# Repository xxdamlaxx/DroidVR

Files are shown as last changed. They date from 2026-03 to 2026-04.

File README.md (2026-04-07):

# 🥽 DroidVR

A DIY VR controller ecosystem — open-source hardware and firmware for SteamVR-compatible motion controllers.

---

## License

DroidVR is available under a **dual license** model. Pick whichever fits your use case.

### Option 1 — Free & Open (Attribution Required)

Use, modify, distribute, and sell DroidVR for free, as long as you provide clear and visible attribution in your project's documentation, about page, and repository.

**Required attribution:**

> Built with **DroidVR** by [xxdamlaxx](https://github.com/xxdamlaxx)

See [`LICENSE.md`](LICENSE.md) for full terms.

### Option 2 — Commercial License (No Attribution)

If you prefer not to include attribution, you can purchase a commercial license:

| Tier | Monthly Fee |
|---|---|
| Public / Open-Source Development | $500 / month |
| Private / Closed-Source Development | $5,000 / month |

- Prices may be adjusted at the end of each calendar year.
- No refunds.

See [`LICENSE-COMMERCIAL.md`](LICENSE-COMMERCIAL.md) for full terms.

---

## Contact

For commercial licensing inquiries, reach out via [GitHub](https://github.com/xxdamlaxx) or email *(coming soon)*.

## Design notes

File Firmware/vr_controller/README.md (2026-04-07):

# DIY VR Sağ Kol Kontrolcü

## Donanım

**Verici (kol):** BluePill STM32F103C8T6
- MPU6500 (I2C): SCL→PB6, SDA→PB7
- NRF24L01 (SPI1): SCK→PA5, MISO→PA6, MOSI→PA7, CSN→PA4, CE→PB0
- Joystick: VRx→PA0, VRy→PA1, SW→PB10
- Tetik pot (20K): Signal→PA3
- VCC→3.3V, GND→GND (hepsi)
- NRF24 VCC-GND arasına 10-100µF kapasitör

**Alıcı (PC):** Wemos D1 Mini + E01-ML01DP5
- SCK→D5, MISO→D6, MOSI→D7, CSN→D8, CE→D1
- VCC→3.3V, GND→GND

## Arduino IDE Kurulumu

### Kütüphaneler (Library Manager'dan kur):
- RF24 by TMRh20

### Verici board ayarları:
- Board: Generic STM32F1 series
- Board part number: BluePill F103C8
- Upload method: STLink veya Serial

### Alıcı board ayarları:
- Board: LOLIN(WEMOS) D1 mini

## SteamVR Sürücü Derleme

1. OpenVR SDK indir: https://github.com/ValveSoftware/openvr → C:\openvr'a çıkar
2. Visual Studio 2022 Community kur (C++ Desktop development workload)
3. CMake kur: https://cmake.org/download/
4. Komut satırında:
```
cd steamvr_driver
mkdir build && cd build
cmake .. -DOPENVR_SDK_DIR="C:/openvr"
cmake --build . --config Release
```
5. `diyvr` klasörünü kopyala: `Steam\steamapps\common\SteamVR\drivers\diyvr`
6. `default.vrsettings` içinde COM port numarasını düzenle (Wemos hangi porta bağlıysa)

## Test

1. Vericiye kodu yükle, Serial Monitor'de "Verici hazir!" mesajını gör
2. Alıcıya kodu yükle, Serial Monitor'de "$VR,..." verilerini gör
3. SteamVR'ı aç, sağ el kontrolcüsü görünmeli
4. Kolu hareket ettirince SteamVR'da dönmeli

## Notlar

- Bu 3DOF (sadece rotasyon). Pozisyonel tracking yok.
- MPU6500 sahte çıkarsa WHO_AM_I 0x70 dönmez, Serial'de hata mesajı görürsün.
- MPU6050 da destekleniyor (0x68 döner), otomatik algılar.
- default.vrsettings'de offset değerleri kontrolcünün SteamVR'daki sabit pozisyonunu belirler.

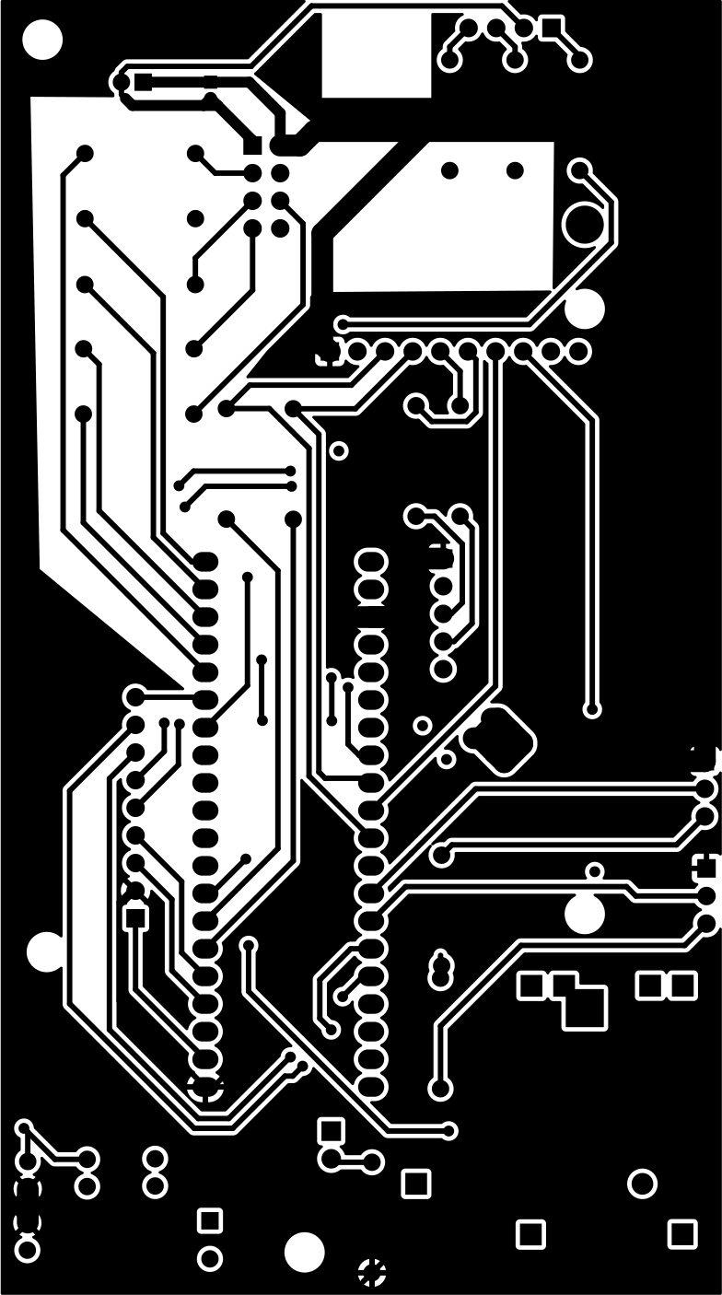
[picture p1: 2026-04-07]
EasyDroidVR_PCB/EasyDroidVR_PCB-backups.png

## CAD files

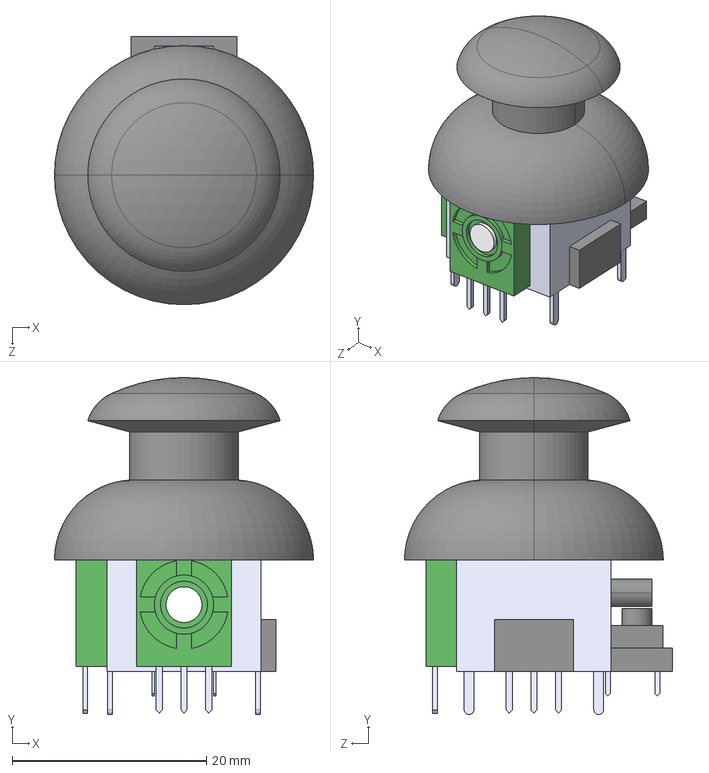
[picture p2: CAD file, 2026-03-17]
EasyDroidVR_PCB/COM-09032/COM-09032.step
26.7 x 34.7 x 27.6 mm

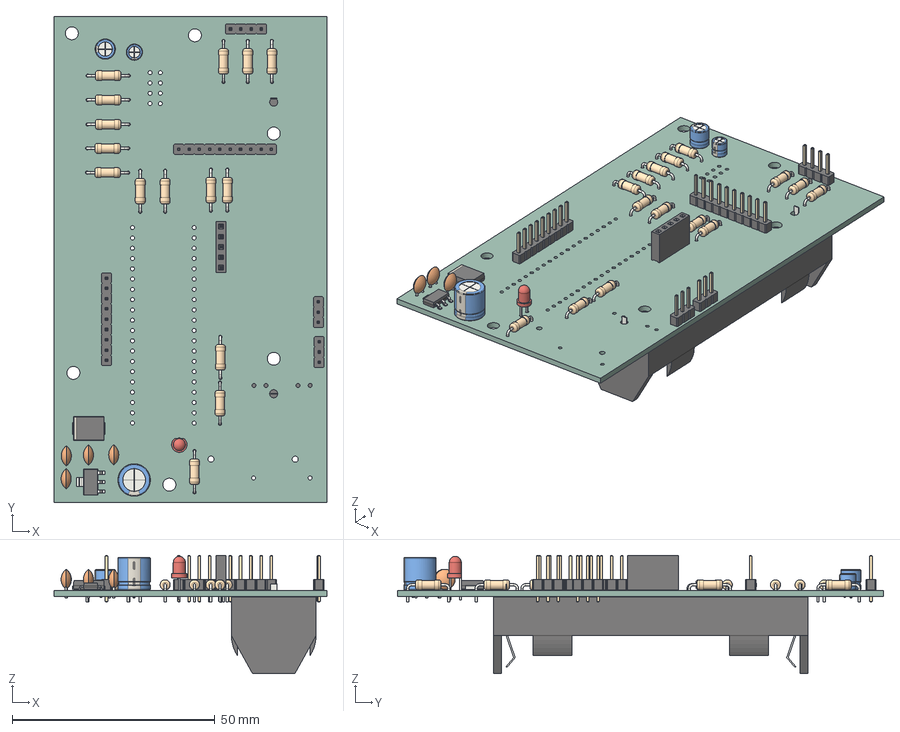
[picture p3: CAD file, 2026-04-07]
EasyDroidVR_PCB/EasyDroidVR_PCB.step
67.3 x 120.0 x 29.2 mm
R_Axial_DIN0207_L6.3mm_D2.5mm_P10.16mm_Horizontal x 15
LED_D3.0mm
C_Disc_D5.0mm_W2.5mm_P2.50mm x 4
PinHeader_1x03_P2.54mm_Vertical x 2
CP_Radial_D5.0mm_P2.00mm
PinHeader_1x09_P2.54mm_Vertical
PinHeader_1x10_P2.54mm_Vertical
CP_Radial_D4.0mm_P1.50mm
PinHeader_1x04_P2.54mm_Vertical
D_SMC
CP_Radial_D8.0mm_P3.50mm
PinSocket_1x05_P2.54mm_Vertical
SOT-223
BatteryHolder_MPD_BH-18650-PC2
EasyDroidVR_PCB_PCB

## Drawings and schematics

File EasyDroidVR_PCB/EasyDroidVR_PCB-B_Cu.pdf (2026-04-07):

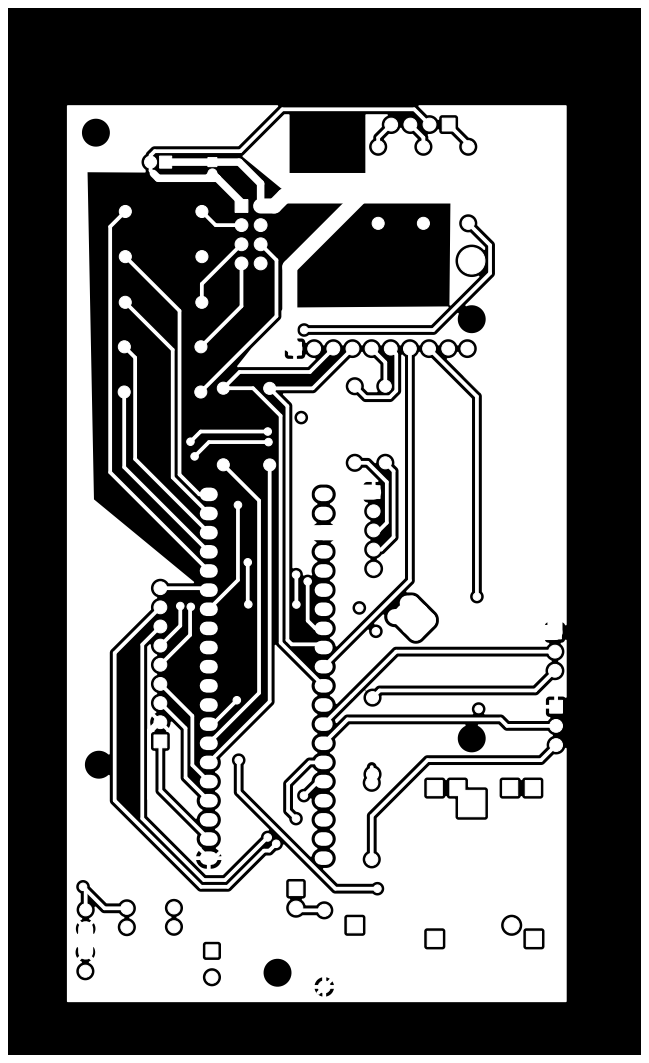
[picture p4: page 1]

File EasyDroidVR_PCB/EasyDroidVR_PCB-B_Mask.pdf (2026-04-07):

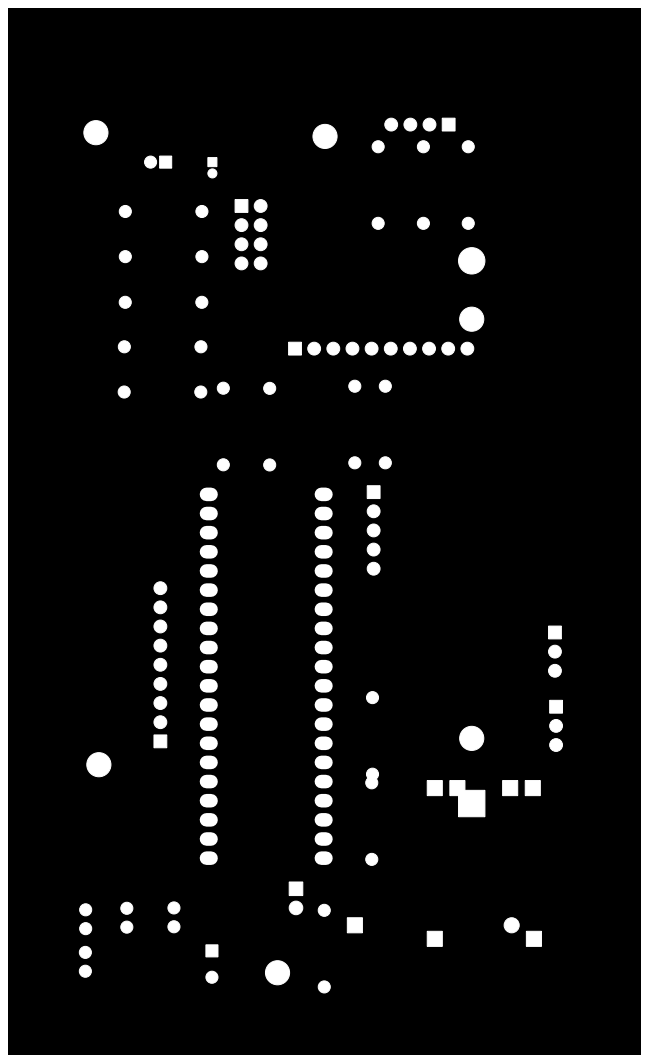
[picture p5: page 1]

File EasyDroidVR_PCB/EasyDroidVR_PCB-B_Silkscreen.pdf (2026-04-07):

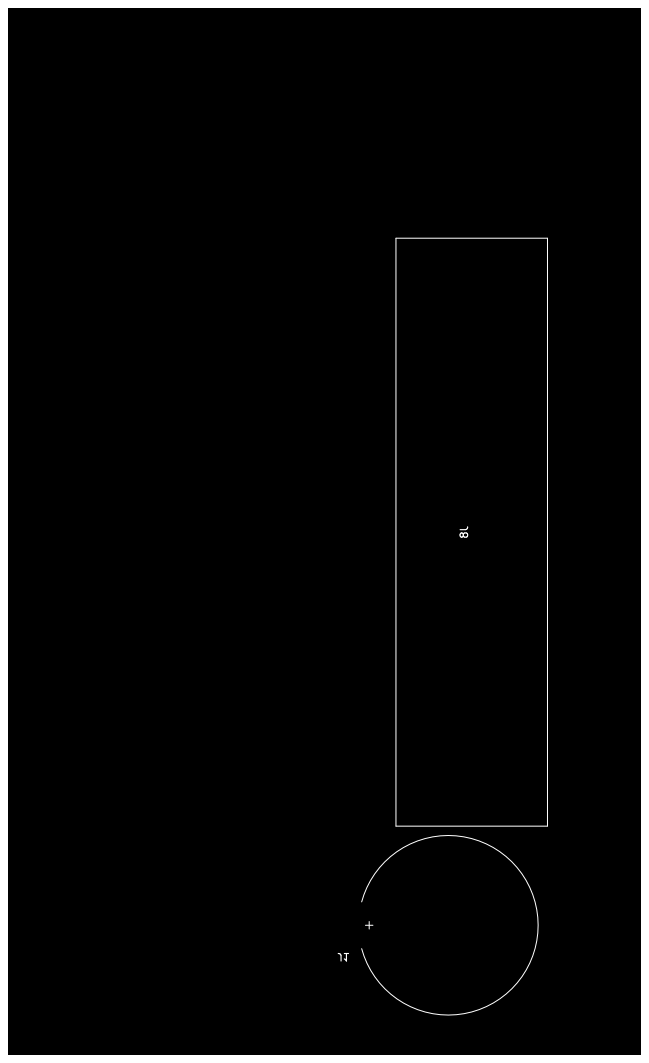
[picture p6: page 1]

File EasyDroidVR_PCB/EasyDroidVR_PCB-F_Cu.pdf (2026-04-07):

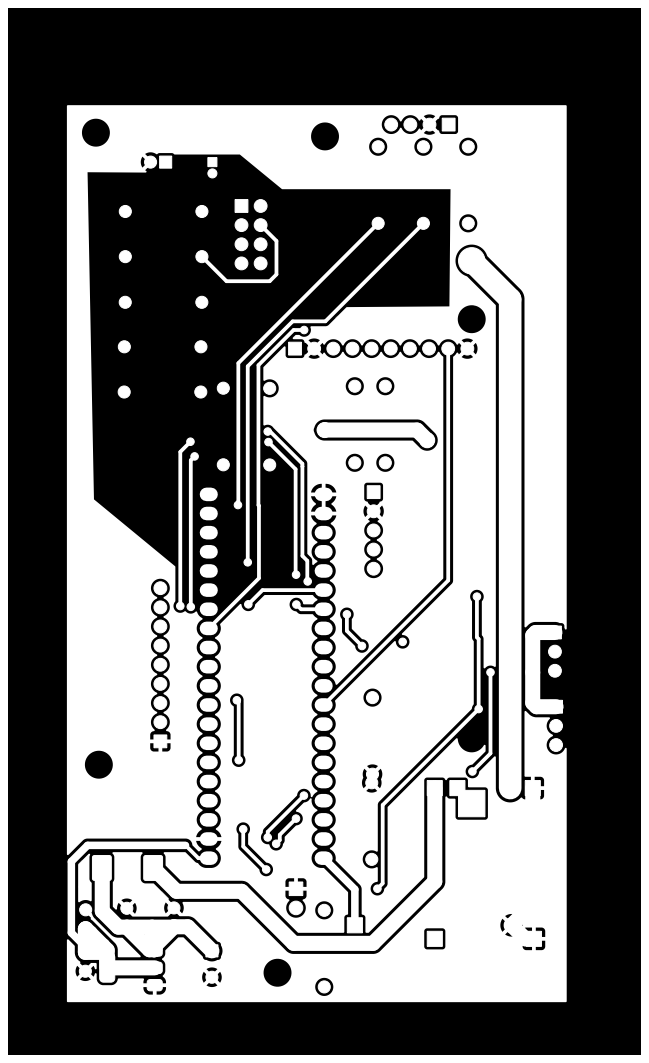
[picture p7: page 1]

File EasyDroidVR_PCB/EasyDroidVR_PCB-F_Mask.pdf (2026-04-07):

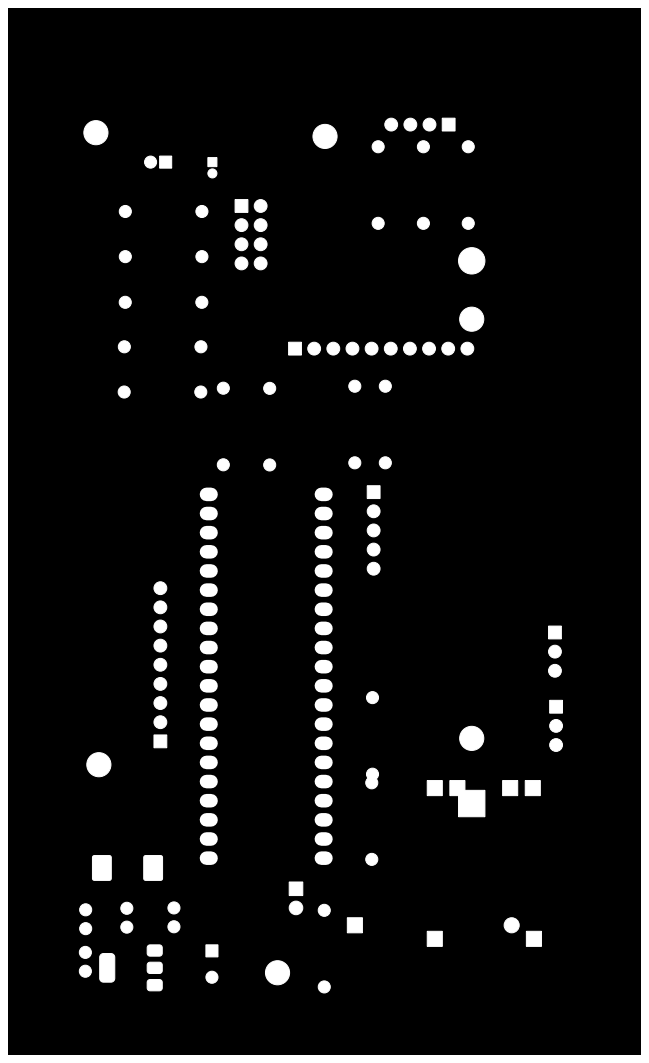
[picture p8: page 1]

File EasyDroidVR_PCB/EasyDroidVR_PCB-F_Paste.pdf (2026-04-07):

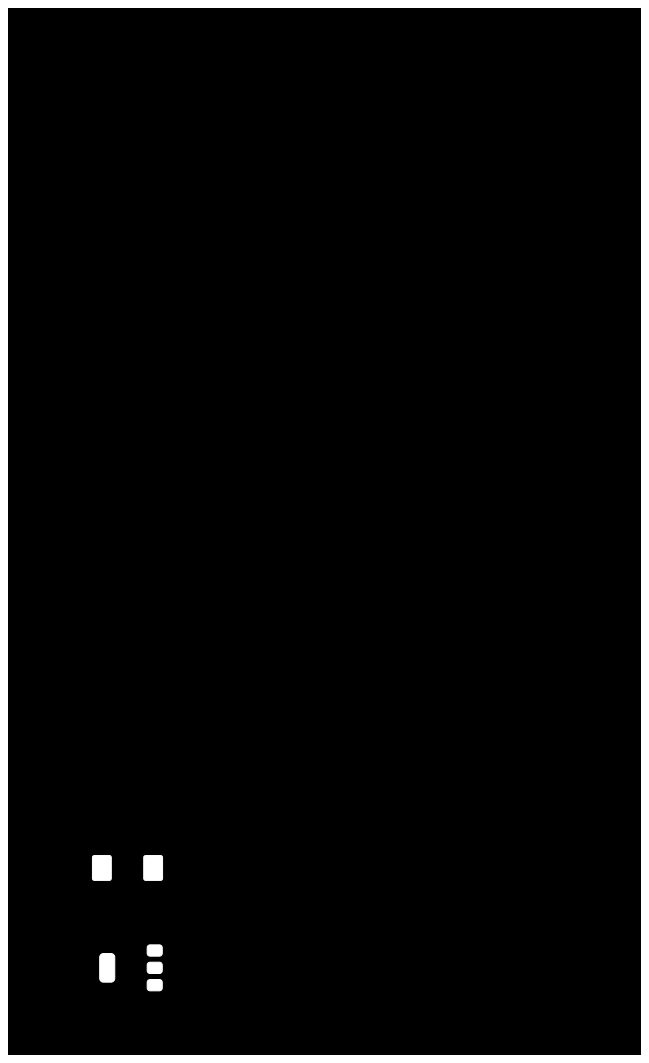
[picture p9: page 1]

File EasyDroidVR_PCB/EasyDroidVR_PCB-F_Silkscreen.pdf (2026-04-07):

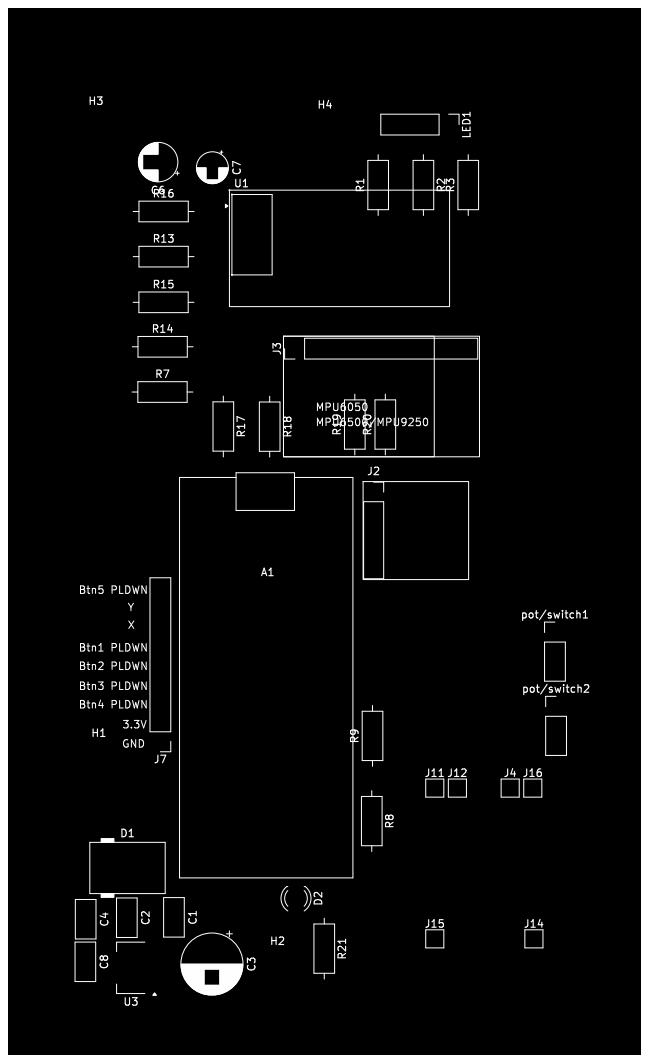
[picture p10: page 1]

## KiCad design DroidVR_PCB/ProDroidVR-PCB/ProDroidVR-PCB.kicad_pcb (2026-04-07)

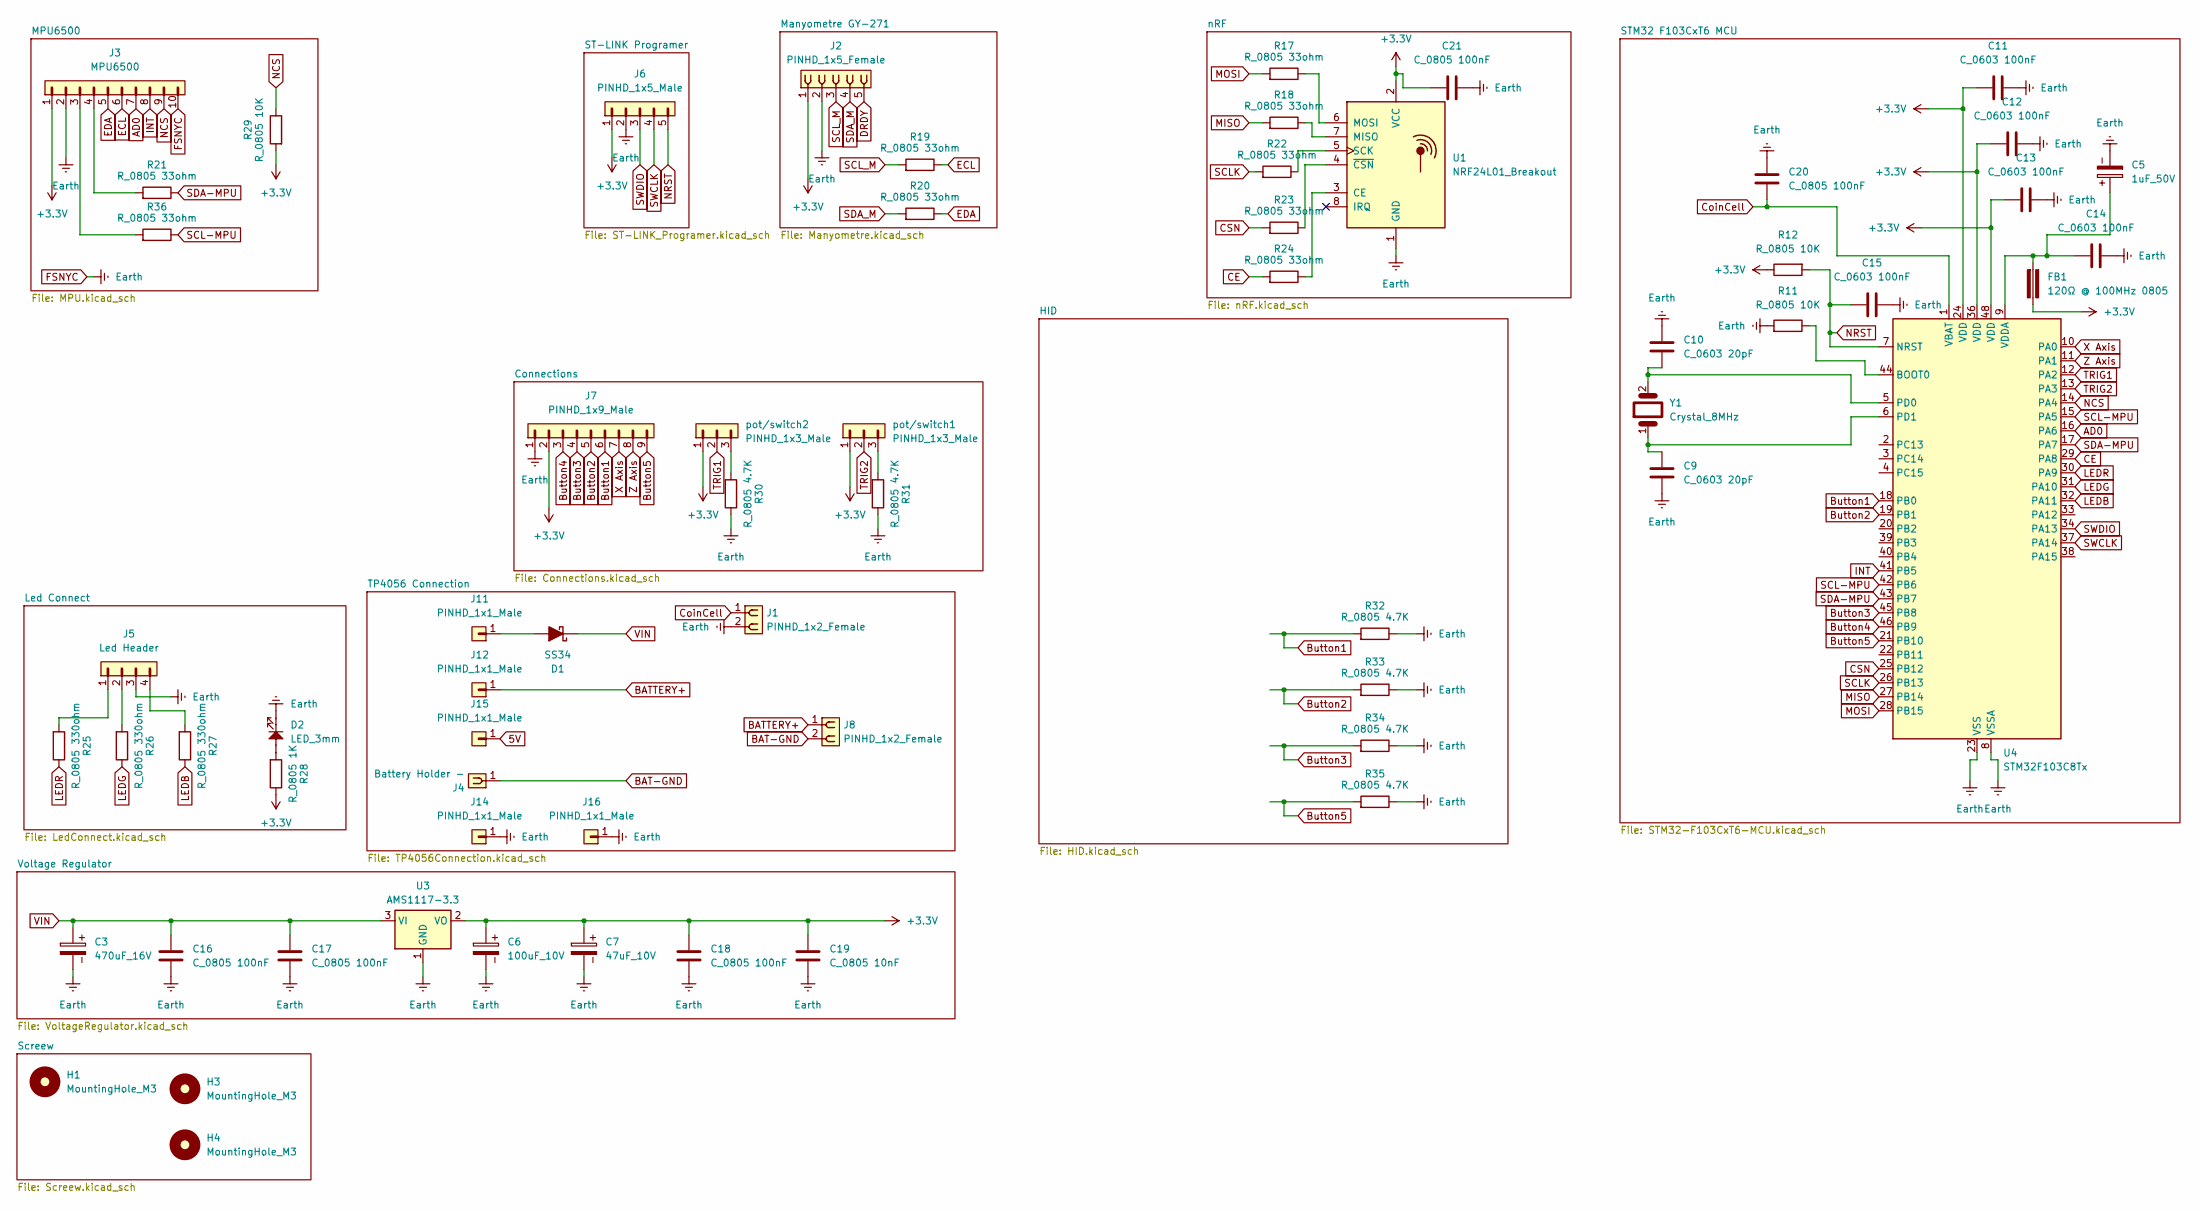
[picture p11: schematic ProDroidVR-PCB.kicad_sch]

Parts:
C3: 470uF_16V; CP_Radial_D8.0mm_P3.50mm
C5: 1uF_50V; CP_Radial_D4.0mm_P1.50mm
C6: 100uF_10V; CP_Radial_D5.0mm_P2.00mm
C7: 47uF_10V; CP_Radial_D4.0mm_P1.50mm
C9, C10: C_0603 20pF; C_0603_1608Metric
C11, C12, C13, C14, C15: C_0603 100nF; C_0603_1608Metric
C16, C17, C18, C20, C21: C_0805 100nF; C_0805_2012Metric
C19: C_0805 10nF; C_0805_2012Metric
D1: SS34; D_SMC
D2: LED_3mm; LED_D3.0mm
FB1: 120Ω @ 100MHz 0805; R_0805_2012Metric
H1, H3, H4: MountingHole_M3; MountingHole_3.2mm_M3
J1: PINHD_1x2_Female; BatteryHolder_MYOUNG_BS-07-A1BJ001_CR2032
J2: PINHD_1x5_Female; PinSocket_1x05_P2.54mm_Vertical
J3: MPU6500; PinHeader_1x10_P2.54mm_Vertical
J4: Battery Holder -; TestPoint_THTPad_2.0x2.0mm_Drill1.0mm
J5: Led Header; PinHeader_1x04_P2.54mm_Vertical
J6: PINHD_1x5_Male; PinHeader_1x05_P2.54mm_Vertical
J7: PINHD_1x9_Male; PinHeader_1x09_P2.54mm_Vertical
J8: PINHD_1x2_Female; BatteryHolder_MPD_BH-18650-PC2
J11, J12, J14, J15, J16: PINHD_1x1_Male; TestPoint_THTPad_2.0x2.0mm_Drill1.0mm
R11, R12, R29: R_0805 10K; R_0805_2012Metric
R17, R18, R19, R20, R21, R22, R23, R24, R36: R_0805 33ohm; R_0805_2012Metric
R25, R26, R27: R_0805 330ohm; R_0805_2012Metric
R28: R_0805 1K; R_0805_2012Metric
R30, R31, R32, R33, R34, R35: R_0805 4.7K; R_0805_2012Metric
U1: NRF24L01_Breakout; nRF24L01_Breakout
U3: AMS1117-3.3; SOT-223-3_TabPin2
U4: STM32F103C8Tx; LQFP-48_7x7mm_P0.5mm
Y1: Crystal_8MHz; Crystal_HC49-4H_Vertical
pot/switch1, pot/switch2: PINHD_1x3_Male; PinHeader_1x03_P2.54mm_Vertical

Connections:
5V: J15.1
+3.3V: C6.1, C7.1, C11.1, C12.1, C13.1, C18.2, C19.2, C21.2, FB1.2, J2.1, J3.1, J6.1, J7.2, R12.2, R28.2, R29.1, U1.2 (VCC), U3.2 (VO), U4.24 (VDD), U4.36 (VDD), U4.48 (VDD), pot/switch1.1, pot/switch2.1
AD0: J3.7, U4.16 (PA6)
BAT-GND: J4.1, J8.2
BATTERY+: J8.1, J12.1
Button1: J7.6, R32.1, U4.18 (PB0)
Button2: J7.5, R33.1, U4.19 (PB1)
Button3: J7.4, R34.1, U4.45 (PB8)
Button4: J7.3, U4.46 (PB9)
Button5: J7.9, R35.1, U4.21 (PB10)
CE: R24.1, U4.29 (PA8)
CSN: R23.1, U4.25 (PB12)
CoinCell: C20.2, J1.1, U4.1 (VBAT)
DRDY: J2.5
ECL: J3.6, R19.2
EDA: J3.5, R20.2
FSNYC: C3.2, C5.2, C6.2, C7.2, C9.2, C10.1, C11.2, C12.2, C13.2, C14.2, C15.2, C16.1, C17.1, C18.1, C19.1, C20.1, C21.1, D2.1, J1.2, J2.2, J3.2, J3.10, J5.3, J6.2, J7.1, J14.1, J16.1, R11.1, R30.2, R31.2, R32.2, R33.2, R34.2, R35.2, U1.1 (GND), U3.1 (GND), U4.8 (VSSA), U4.23 (VSS), U4.35 (VSS), U4.47 (VSS)
INT: J3.8, U4.41 (PB5)
LEDB: R27.2, U4.32 (PA11)
LEDG: R26.2, U4.31 (PA10)
LEDR: R25.2, U4.30 (PA9)
MISO: R18.1, U4.27 (PB14)
MOSI: R17.1, U4.28 (PB15)
NCS: J3.9, R29.2, U4.14 (PA4)
NRST: C15.1, J6.5, R12.1, U4.7 (NRST)
unnamed: D1.2 (A), J11.1
unnamed: D2.2, R28.1
unnamed: J3.3, R36.1
unnamed: J3.4, R21.1
unnamed: J5.1, R25.1
unnamed: J5.2, R26.1
unnamed: J5.4, R27.1
unnamed: R30.1, pot/switch2.3
unnamed: R31.1, pot/switch1.3
unnamed: R24.2, U1.3 (CE)
unnamed: R18.2, U1.7 (MISO)
unnamed: R17.2, U1.6 (MOSI)
unnamed: R22.2, U1.5 (SCK)
unnamed: R23.2, U1.4 (~CSN)
unnamed: R11.2, U4.44 (BOOT0)
unnamed: C10.2, U4.5 (PD0), Y1.2
unnamed: C9.1, U4.6 (PD1), Y1.1
unnamed: C5.1, C14.1, FB1.1, U4.9 (VDDA)
SCL-MPU: R36.2, U4.15 (PA5), U4.42 (PB6)
SCLK: R22.1, U4.26 (PB13)
SCL_M: J2.3, R19.1
SDA-MPU: R21.2, U4.17 (PA7), U4.43 (PB7)
SDA_M: J2.4, R20.1
SWCLK: J6.4, U4.37 (PA14)
SWDIO: J6.3, U4.34 (PA13)
TRIG1: U4.12 (PA2), pot/switch2.2
TRIG2: U4.13 (PA3), pot/switch1.2
VIN: C3.1, C16.2, C17.2, D1.1 (K), U3.3 (VI)
X Axis: J7.7, U4.10 (PA0)
Z Axis: J7.8, U4.11 (PA1)

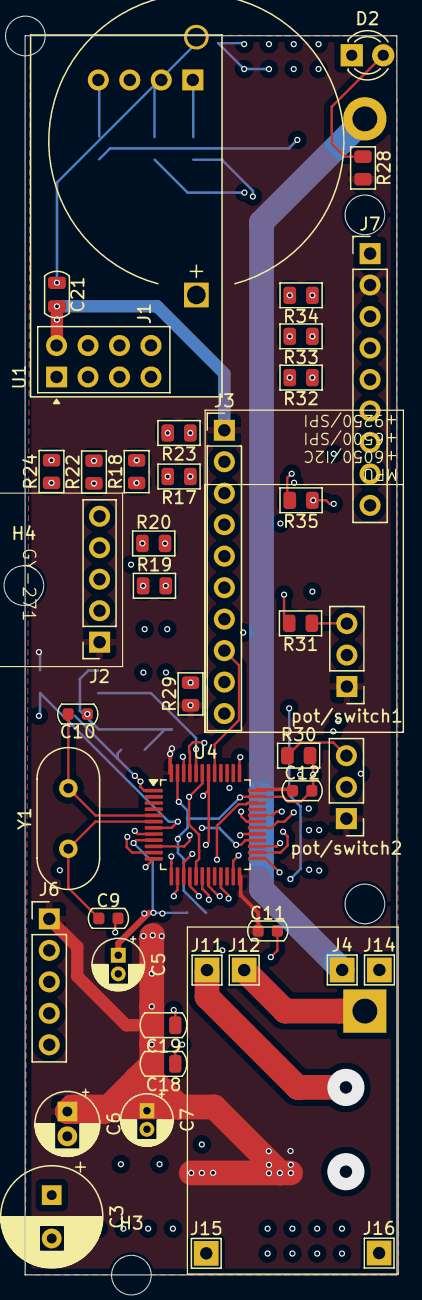
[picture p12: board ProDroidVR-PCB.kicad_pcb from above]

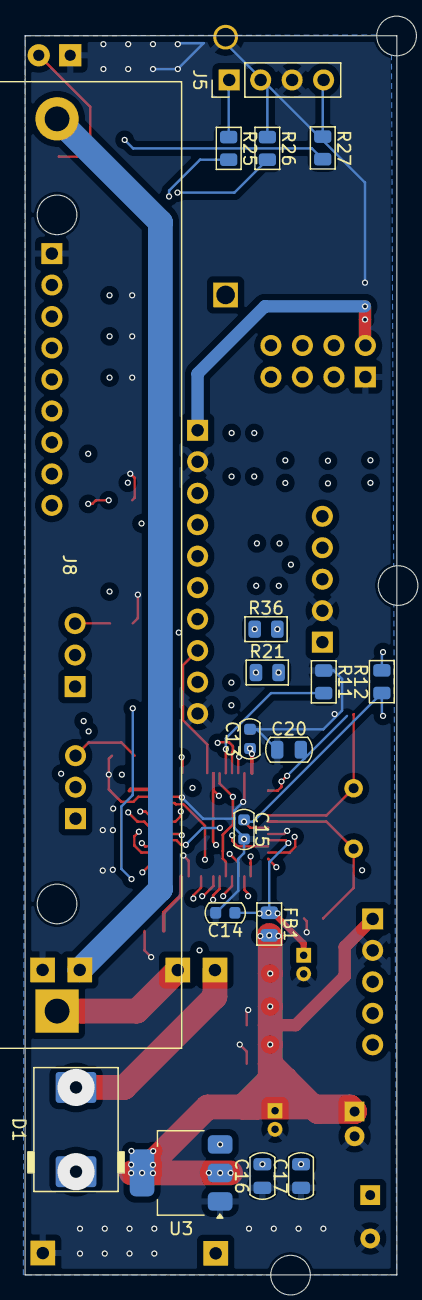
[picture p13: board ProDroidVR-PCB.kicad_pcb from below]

Board: 4 copper layers, 30.0 x 100.0 mm, 64 parts (18 on the bottom side), 53 nets.

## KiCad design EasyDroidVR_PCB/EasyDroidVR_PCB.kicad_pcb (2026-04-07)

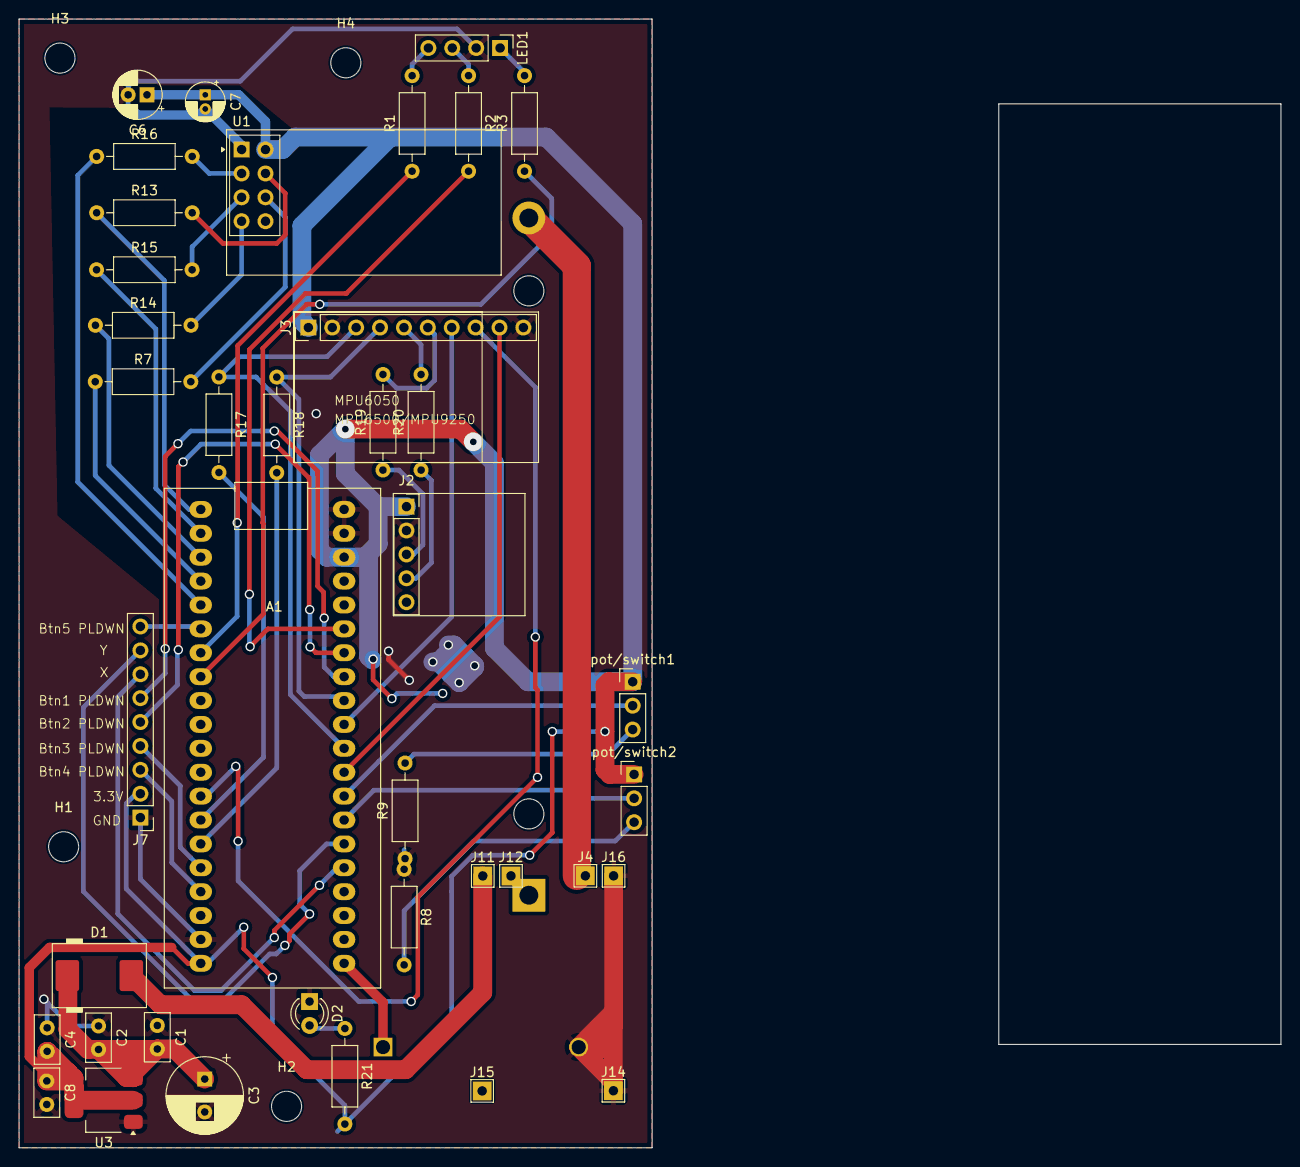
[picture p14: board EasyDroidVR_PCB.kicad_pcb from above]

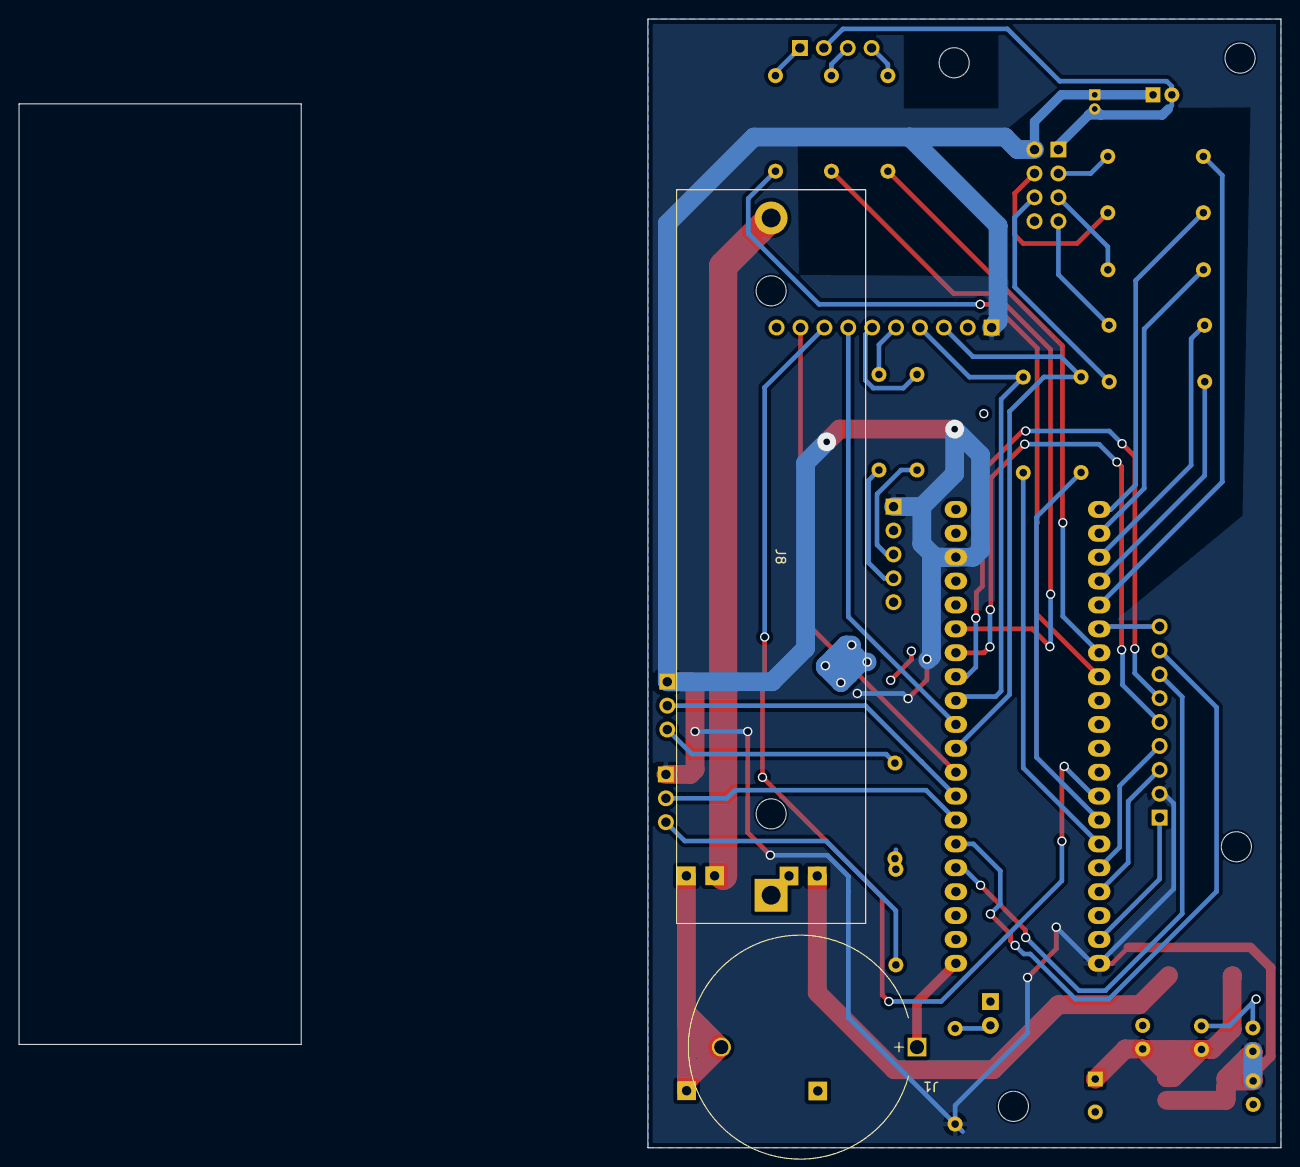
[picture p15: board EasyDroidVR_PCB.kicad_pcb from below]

Board: 2 copper layers, 67.3 x 120.0 mm, 45 parts (2 on the bottom side), 46 nets.

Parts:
A1: STM32_Blue_Pill_DevBoard
C1, C2, C4: 100nF_Ceramic; C_Disc_D5.0mm_W2.5mm_P2.50mm
C3: 470uF_16V; CP_Radial_D8.0mm_P3.50mm
C6: 100uF_10V; CP_Radial_D5.0mm_P2.00mm
C7: 47uF_10V; CP_Radial_D4.0mm_P1.50mm
C8: 10nF_Ceramic; C_Disc_D5.0mm_W2.5mm_P2.50mm
D1: SS34; D_SMC
D2: LED_3mm; LED_D3.0mm
H1, H2, H3, H4: MountingHole_M3; MountingHole_3.2mm_M3
J1: PINHD_1x2_Female; BatteryHolder_MYOUNG_BS-07-A1BJ001_CR2032
J2: PINHD_1x5_Female; PinSocket_1x05_P2.54mm_Vertical
J3: MPU6500; PinHeader_1x10_P2.54mm_Vertical
J4: Battery Holder -; TestPoint_THTPad_2.0x2.0mm_Drill1.0mm
J7: PINHD_1x9_Male; PinHeader_1x09_P2.54mm_Vertical
J8: PINHD_1x2_Female; BatteryHolder_MPD_BH-18650-PC2
J11, J12, J14, J15, J16: PINHD_1x1_Male; TestPoint_THTPad_2.0x2.0mm_Drill1.0mm
LED1: LED_5mm_RGB_Kcom_BKRG; PinHeader_1x04_P2.54mm_Vertical
R1, R2, R3: 330ohm; R_Axial_DIN0207_L6.3mm_D2.5mm_P10.16mm_Horizontal
R7, R13, R14, R15, R16, R17, R18, R19, R20: 33ohm; R_Axial_DIN0207_L6.3mm_D2.5mm_P10.16mm_Horizontal
R8, R9: 4.7k; R_Axial_DIN0207_L6.3mm_D2.5mm_P10.16mm_Horizontal
R21: 1k; R_Axial_DIN0207_L6.3mm_D2.5mm_P10.16mm_Horizontal
U1: NRF24L01_Breakout; nRF24L01_Breakout
U3: AMS1117-3.3; SOT-223-3_TabPin2
pot/switch1, pot/switch2: PINHD_1x3_Male; PinHeader_1x03_P2.54mm_Vertical

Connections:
+3.3V: A1.20 (3V3), A1.38 (3V3), C4.2, C6.1, C7.1, C8.1, J2.1, J3.1, J7.2, R21.2, U1.2 (VCC), U3.2 (VO), pot/switch1.1, pot/switch2.1
AD0: A1.31 (MISO1/PA6), J3.7
BAT-GND: J4.1, J8.2
BATTERY+: J8.1, J12.1
Button1: A1.33 (PB0), J7.6
Button2: A1.34 (PB1), J7.5
Button3: A1.16 (PB8/SCL1), J7.4
Button4: A1.17 (PB9/SDA1), J7.3
Button5: A1.6 (PA9/TX1), J7.9
CE: A1.5 (PA8/CK1), R16.1
CSN: A1.1 (PB12/NSS2), R13.1
CoinCell: A1.21 (VBAT), J1.1
ECL: J3.6, R19.2
EDA: J3.5, R20.2
FSNYC: A1.19 (GND), A1.39 (GND), A1.40 (GND), C1.1, C2.1, C3.2, C4.1, C6.2, C7.2, C8.2, D2.1, J1.2, J2.2, J3.2, J3.10, J7.1, J14.1, J16.1, LED1.2 (A), R8.1, R9.1, U1.1 (GND), U3.1 (GND)
INT: A1.13 (PB5/MOSI1), J3.8
LEDB: A1.8 (PA11/~USB-), R3.1
LEDG: A1.7 (PA10/RX1), R1.1
LEDR: A1.35 (SCL2/TX3/PB10), R2.2
MISO: A1.3 (PB14/MISO2), R14.1
MOSI: A1.4 (PB15/MOSI2), R7.1
NCS: A1.29 (NSS1/PA4), J3.9
unnamed: A1.14 (PB6/SCL1/TX1), R17.2
unnamed: A1.15 (PB7/SDA1/RX1), R18.2
unnamed: D1.2 (A), J11.1
unnamed: D2.2, R21.1
unnamed: LED1.1 (B), R3.2
unnamed: LED1.4 (G), R1.2
unnamed: LED1.3 (R), R2.1
unnamed: R8.2, pot/switch2.3
unnamed: R9.2, pot/switch1.3
unnamed: R16.2, U1.3 (CE)
unnamed: R14.2, U1.7 (MISO)
unnamed: R7.2, U1.6 (MOSI)
unnamed: R15.2, U1.5 (SCK)
unnamed: R13.2, U1.4 (~CSN)
SCL: A1.30 (SCK1/PA5), J3.3, R17.1
SCLK: A1.2 (PB13/SCK2), R15.1
SCL_M: J2.3, R19.1
SDA: A1.32 (MOSI1/PA7), J3.4, R18.1
SDA_M: J2.4, R20.1
TRIG1: A1.27 (TX2/PA2), pot/switch2.2
TRIG2: A1.28 (RX2/PA3), pot/switch1.2
VIN: C1.2, C2.2, C3.1, D1.1 (K), U3.3 (VI)
X Axis: A1.25 (PA0), J7.7
Z Axis: A1.26 (PA1), J7.8

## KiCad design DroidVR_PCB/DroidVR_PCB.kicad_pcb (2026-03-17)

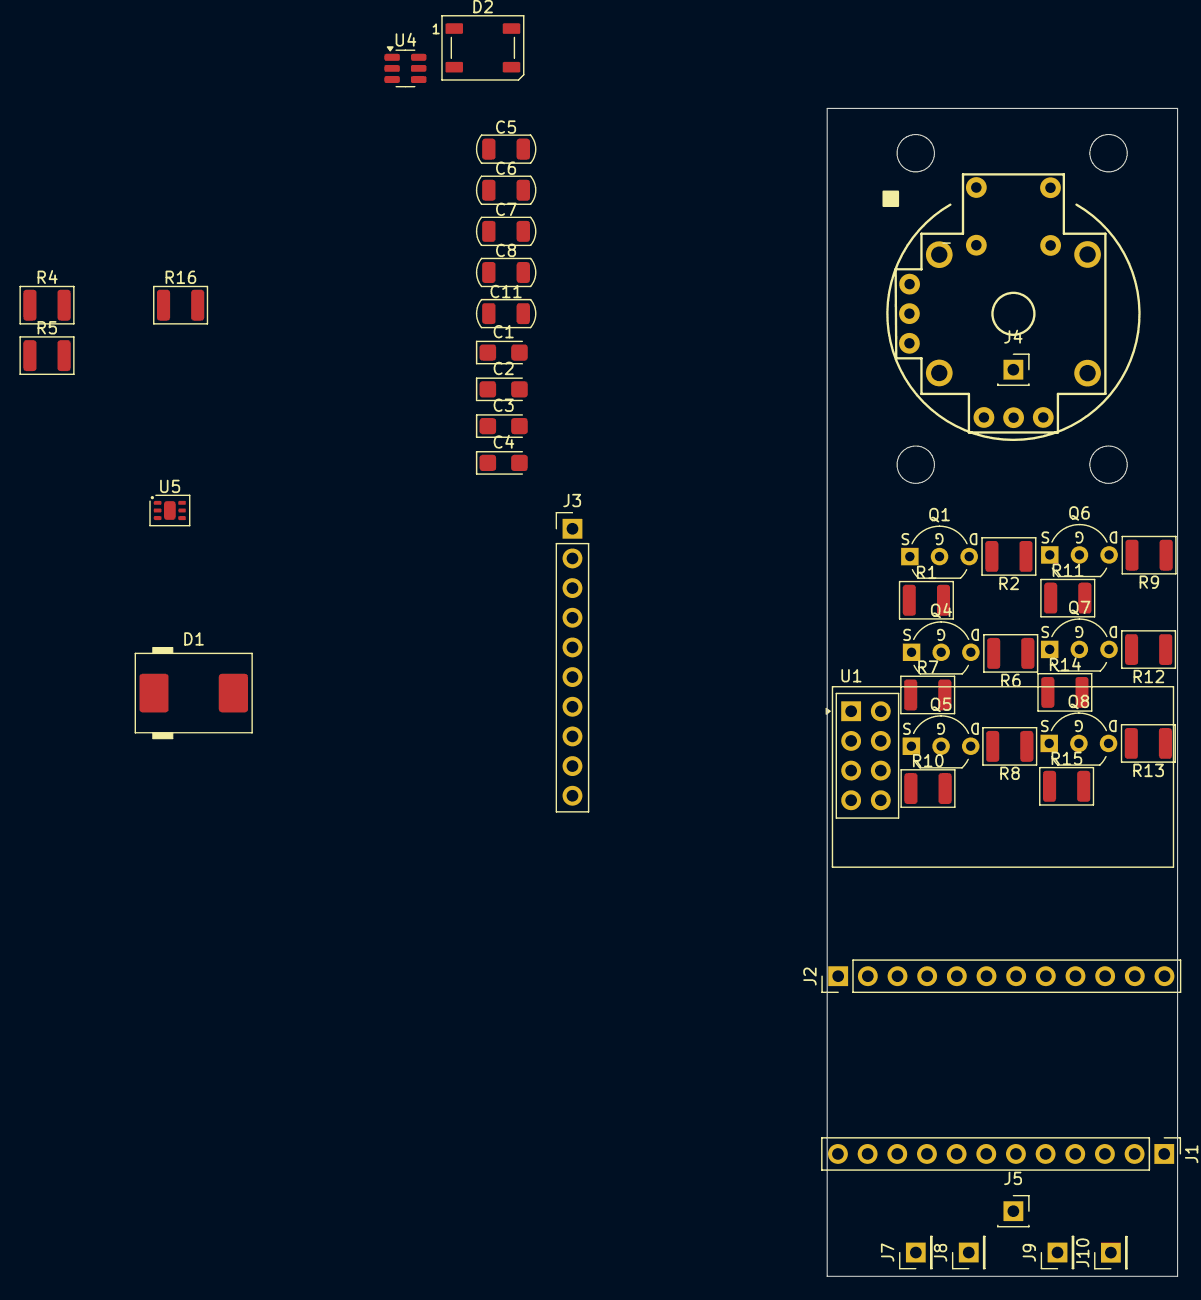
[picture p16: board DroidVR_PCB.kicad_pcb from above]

Board: 2 copper layers, 30.0 x 100.0 mm, 49 parts (0 on the bottom side), 20 nets, no tracks yet.

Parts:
C1: C_Polarized 10uF/10V+; CP_EIA-3216-18_Kemet-A
C2: C_Polarized 10uF/16V+; CP_EIA-3216-18_Kemet-A
C3: C_Polarized 22uF/6.3V+; CP_EIA-3216-18_Kemet-A
C4: C_Polarized 22uF/10V+; CP_EIA-3216-18_Kemet-A
C5, C6, C7, C8, C11: C_1206 100nF; C_1206_3216Metric
D1: SS34; D_SMC
D2: WS2812B; LED_WS2812B_PLCC4_5.0x5.0mm_P3.2mm
H1, H2, H3, H4: MountingHole; MountingHole_3.2mm_M3_DIN965
J1, J2: PINHD_1x12_Male; PinHeader_1x12_P2.54mm_Vertical
J3: MPU6500; PinHeader_1x10_P2.54mm_Vertical
J4: Battery Holder -; PinSocket_1x01_P2.54mm_Vertical
J5: Battery Holder +; PinSocket_1x01_P2.54mm_Vertical
J7, J8, J9, J10: PINHD_1x1_Male; PinHeader_1x01_P2.54mm_Vertical
Q1, Q4, Q5, Q6, Q7, Q8: 2N7000; TO-92_Inline_Wide_SGD
R1, R2, R6, R7, R8, R9, R10, R11, R12, R13, R14, R15: R_1210 4.7KOhm; R_1210_3225Metric
R4, R5: R_1210 5.1KOhm; R_1210_3225Metric
R16: R_1210 330Ohm; R_1210_3225Metric
U1: COM-09032; XDCR_COM-09032
U1#2: NRF24L01_Breakout; nRF24L01_Breakout
U4: MT3608; SOT-23-6
U5: MCP1700T-3002E-MAY; DFN-6-1EP_2x2mm_P0.65mm_EP1x1.6mm

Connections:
+3.3V: C1.1, C3.1, J3.1, Q1.2 (G), Q4.2 (G), Q5.2 (G), Q6.2 (G), Q7.2 (G), Q8.2 (G), R1.2, R7.2, R10.2, R11.2, R14.2, R15.2, U1#2.2 (VCC), U5.6 (OUT)
+5V: C2.1, C4.1, C7.1, C8.1, D2.1 (VDD), J2.9, R2.1, R6.1, R9.1, R12.1, R13.1, U1.B1A (SEL+), U1.H1 (H+), U1.V1 (V+), U5.1 (IN)
A8: J3.9, Q8.1 (S), R15.1
A8_A: J1.11, Q8.3 (D), R13.2
A9: Q7.1 (S), R14.1, U1#2.3 (CE)
A9_A: J1.12, Q7.3 (D), R12.2
A10: Q6.1 (S), R11.1, U1#2.4 (~CSN)
A10_A: J2.1, Q6.3 (D), R9.2
AmperMater: C1.2, C2.2, C3.2, C4.2, C5.2, C6.2, C7.2, C8.2, C11.1, D2.3 (VSS), J1.3, J1.4, J2.11, J3.2, J3.10, R4.1, R5.1, U1#2.1 (GND), U4.2 (GND), U5.3, U5.7
Li-ion: D1.2 (A), J5.1
MISO: J3.7, Q4.1 (S), R7.1, U1#2.7 (MISO)
MISO_A: J2.3, Q4.3 (D), R6.2
MOSI: J3.4, Q5.1 (S), R10.1, U1#2.6 (MOSI)
MOSI_A: J2.2, Q5.3 (D), R8.2
unnamed: D2.4 (DIN), R16.1
unnamed: U1.S1 (SHIELD), U1.S2 (SHIELD), U1.S3 (SHIELD), U1.S4 (SHIELD)
SCLK: J3.3, Q1.1 (S), R1.1, U1#2.5 (SCK)
SCLK_A: J2.4, Q1.3 (D), R2.2
TX: J1.1, R16.2
VIN: C5.1, C6.1, D1.1 (K), U4.4 (EN), U4.5 (IN)

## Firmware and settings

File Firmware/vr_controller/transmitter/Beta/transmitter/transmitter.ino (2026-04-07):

/*
 * DIY VR Sağ Kol - Verici (BluePill STM32F103C8T6)
 * 
 * Bağlantılar:
 *   MPU6050/6500 (I2C1): SCL→PB6, SDA→PB7, VCC→3.3V, GND→GND
 *   NRF24L01 (SPI1):     SCK→PA5, MISO→PA6, MOSI→PA7, CSN→PA4, CE→PB0
 *   Joystick:             VRx→PA0, VRy→PA1, SW→PB10
 *   Tetik pot (20K):      Signal→PA3
 * 
 * Board:      Generic STM32F1 series → BluePill F103C8
 * Upload:     STLink veya Serial
 * Kütüphane:  RF24 by TMRh20
 */

#include <Wire.h>
#include <SPI.h>
#include <RF24.h>

// ===== TANIMLAR =====
#ifndef DEG_TO_RAD
  #define DEG_TO_RAD 0.017453292519943295f
#endif

// ===== AYARLANABILIR PARAMETRELER =====
#define LOOP_INTERVAL_US    5000    // 5ms = 200Hz hedef
#define MADGWICK_BETA       0.08f
#define JOY_DEADZONE        30
#define ANALOG_SMOOTH_ALPHA 0.3f
#define GYRO_CAL_SAMPLES    1000
#define NRF_CHANNEL         76
#define SERIAL_DEBUG        1
#define DEBUG_INTERVAL_MS   2000

// ===== PINLER =====
#define NRF_CE   PB0
#define NRF_CSN  PA4
#define JOY_X    PA0
#define JOY_Y    PA1
#define JOY_SW   PB10
#define TRIGGER  PA3

// ===== NRF24 =====
RF24 radio(NRF_CE, NRF_CSN);
const uint64_t pipe = 0xF0F0F0F0E1LL;

// ===== MPU =====
#define MPU_ADDR     0x68
#define WHO_AM_I     0x75
#define PWR_MGMT_1   0x6B
#define CONFIG_REG   0x1A
#define GYRO_CONFIG  0x1B
#define ACCEL_CONFIG 0x1C
#define ACCEL_XOUT_H 0x3B

// ===== QUATERNION =====
float qw = 1.0f, qx = 0.0f, qy = 0.0f, qz = 0.0f;
float gxOff = 0.0f, gyOff = 0.0f, gzOff = 0.0f;
unsigned long lastTime = 0;

// ===== ANALOG SMOOTH =====
float smoothJoyX = 0.0f, smoothJoyY = 0.0f, smoothTrig = 0.0f;

// ===== PAKET =====
// !! ALICI VE DRIVER ILE BIREBIR AYNI YAPI !!
// Toplam 24 byte (packed)
struct __attribute__((packed)) Packet {
  float qw, qx, qy, qz;     // 16 byte
  int16_t joyX, joyY;        // 4 byte
  int16_t trigger;            // 2 byte
  uint8_t buttons;            // 1 byte
  uint8_t seq;                // 1 byte
};                            // = 24 byte

Packet pkt;
uint8_t seqCounter = 0;

// ===== ISTATISTIK =====
#if SERIAL_DEBUG
  unsigned long lastPrint = 0;
  uint16_t okCount = 0, failCount = 0;
#endif

// ===========================================================================
//                          MPU FONKSİYONLARI
// ===========================================================================

void mpuWrite(uint8_t reg, uint8_t val) {
  Wire.beginTransmission(MPU_ADDR);
  Wire.write(reg);
  Wire.write(val);
  Wire.endTransmission();
}

uint8_t mpuRead(uint8_t reg) {
  Wire.beginTransmission(MPU_ADDR);
  Wire.write(reg);
  Wire.endTransmission(false);
  Wire.requestFrom(MPU_ADDR, (uint8_t)1);
  return Wire.read();
}

void mpuReadBytes(uint8_t reg, uint8_t* buf, uint8_t len) {
  Wire.beginTransmission(MPU_ADDR);
  Wire.write(reg);
  Wire.endTransmission(false);
  Wire.requestFrom(MPU_ADDR, len);
  for (uint8_t i = 0; i < len; i++) {
    buf[i] = Wire.read();
  }
}

bool initMPU() {
  mpuWrite(PWR_MGMT_1, 0x80);
  delay(150);

  uint8_t id = mpuRead(WHO_AM_I);
  Serial.print("WHO_AM_I: 0x");
  Serial.println(id, HEX);

  if (id == 0x70 || id == 0x71) {
    Serial.println("MPU6500 tespit edildi.");
  } else if (id == 0x68) {
    Serial.println("MPU6050 tespit edildi.");
  } else {
    Serial.print("MPU BULUNAMADI! WHO_AM_I=0x");
    Serial.println(id, HEX);
    return false;
  }

  mpuWrite(PWR_MGMT_1, 0x01);
  delay(10);
  mpuWrite(0x6C, 0x00);
  mpuWrite(CONFIG_REG, 0x03);     // DLPF ~42Hz
  mpuWrite(GYRO_CONFIG, 0x08);    // ±500°/s
  mpuWrite(ACCEL_CONFIG, 0x08);   // ±4g

  delay(50);
  uint8_t dummy[14];
  for (int i = 0; i < 20; i++) {
    mpuReadBytes(ACCEL_XOUT_H, dummy, 14);
    delay(2);
  }
  return true;
}

void calibrateGyro() {
  Serial.print("Gyro kalibrasyonu (HAREKET ETME!)");
  int32_t sx = 0, sy = 0, sz = 0;

  for (int i = 0; i < GYRO_CAL_SAMPLES; i++) {
    uint8_t buf[6];
    mpuReadBytes(0x43, buf, 6);
    sx += (int16_t)(buf[0] << 8 | buf[1]);
    sy += (int16_t)(buf[2] << 8 | buf[3]);
    sz += (int16_t)(buf[4] << 8 | buf[5]);
    delay(2);
    if (i % 200 == 0) Serial.print(".");
  }

  gxOff = (float)sx / GYRO_CAL_SAMPLES;
  gyOff = (float)sy / GYRO_CAL_SAMPLES;
  gzOff = (float)sz / GYRO_CAL_SAMPLES;

  Serial.print(" OK (offset: ");
  Serial.print(gxOff, 1); Serial.print(", ");
  Serial.print(gyOff, 1); Serial.print(", ");
  Serial.print(gzOff, 1); Serial.println(")");
}

// ===========================================================================
//                          MADGWICK FİLTRESİ
// ===========================================================================

void madgwick(float gx, float gy, float gz,
              float ax, float ay, float az, float dt) {

  float q0 = qw, q1 = qx, q2 = qy, q3 = qz;

  float norm = sqrtf(ax * ax + ay * ay + az * az);
  if (norm < 0.001f) return;
  float invNorm = 1.0f / norm;
  ax *= invNorm; ay *= invNorm; az *= invNorm;

  float _2q0 = 2.0f * q0, _2q1 = 2.0f * q1;
  float _2q2 = 2.0f * q2, _2q3 = 2.0f * q3;
  float _4q0 = 4.0f * q0, _4q1 = 4.0f * q1, _4q2 = 4.0f * q2;
  float _8q1 = 8.0f * q1, _8q2 = 8.0f * q2;
  float q0q0 = q0 * q0, q1q1 = q1 * q1;
  float q2q2 = q2 * q2, q3q3 = q3 * q3;

  float s0 = _4q0 * q2q2 + _2q2 * ax + _4q0 * q1q1 - _2q1 * ay;
  float s1 = _4q1 * q3q3 - _2q3 * ax + 4.0f * q0q0 * q1 - _2q0 * ay
             - _4q1 + _8q1 * q1q1 + _8q1 * q2q2 + _4q1 * az;
  float s2 = 4.0f * q0q0 * q2 + _2q0 * ax + _4q2 * q3q3 - _2q3 * ay
             - _4q2 + _8q2 * q1q1 + _8q2 * q2q2 + _4q2 * az;
  float s3 = 4.0f * q1q1 * q3 - _2q1 * ax + 4.0f * q2q2 * q3 - _2q2 * ay;

  norm = sqrtf(s0 * s0 + s1 * s1 + s2 * s2 + s3 * s3);
  if (norm < 0.001f) return;
  invNorm = 1.0f / norm;
  s0 *= invNorm; s1 *= invNorm; s2 *= invNorm; s3 *= invNorm;

  float qDot0 = 0.5f * (-q1 * gx - q2 * gy - q3 * gz) - MADGWICK_BETA * s0;
  float qDot1 = 0.5f * ( q0 * gx + q2 * gz - q3 * gy) - MADGWICK_BETA * s1;
  float qDot2 = 0.5f * ( q0 * gy - q1 * gz + q3 * gx) - MADGWICK_BETA * s2;
  float qDot3 = 0.5f * ( q0 * gz + q1 * gy - q2 * gx) - MADGWICK_BETA * s3;

  q0 += qDot0 * dt;
  q1 += qDot1 * dt;
  q2 += qDot2 * dt;
  q3 += qDot3 * dt;

  norm = sqrtf(q0 * q0 + q1 * q1 + q2 * q2 + q3 * q3);
  invNorm = 1.0f / norm;
  qw = q0 * invNorm;
  qx = q1 * invNorm;
  qy = q2 * invNorm;
  qz = q3 * invNorm;
}

// ===========================================================================
//                          YARDIMCI FONKSİYONLAR
// ===========================================================================

int16_t applyDeadzone(int16_t val, int16_t deadzone) {
  if (val > -deadzone && val < deadzone) return 0;
  return val;
}

float emaFilter(float prev, float raw, float alpha) {
  return prev + alpha * (raw - prev);
}

// ===========================================================================
//                              SETUP
// ===========================================================================

void setup() {
  Serial.begin(115200);
  delay(500);
  Serial.println("\n=== VR Verici Basliyor ===");
  Serial.print("Paket boyutu: ");
  Serial.print(sizeof(Packet));
  Serial.println(" byte");

  pinMode(JOY_SW, INPUT_PULLUP);

  Wire.begin();
  Wire.setClock(400000);

  if (!initMPU()) {
    Serial.println("!!! MPU HATA — Sistem durduruluyor.");
    while (1) delay(1000);
  }
  calibrateGyro();

  Serial.print("NRF24 baslatiliyor... ");
  if (!radio.begin()) {
    Serial.println("BASARISIZ! Kablo baglantisini kontrol et.");
    while (1) delay(1000);
  }
  Serial.println("OK");

  // --- NRF24 AYARLARI — ALICI ILE BIREBIR AYNI OLMALI ---
  radio.setPALevel(RF24_PA_HIGH);
  radio.setDataRate(RF24_1MBPS);          // 1Mbps — daha guvenilir
  radio.setChannel(NRF_CHANNEL);          // Kanal 76
  radio.setPayloadSize(sizeof(Packet));   // 24 byte
  radio.setRetries(3, 5);                 // 1000µs aralik, max 5 deneme
  radio.setAutoAck(true);
  radio.openWritingPipe(pipe);
  radio.stopListening();

  Serial.print("Kanal: "); Serial.println(radio.getChannel());
  Serial.print("DataRate: 1MBPS");
  Serial.println("\n=== Verici Hazir ===\n");

  smoothJoyX = (float)analogRead(JOY_X);
  smoothJoyY = (float)analogRead(JOY_Y);
  smoothTrig = (float)analogRead(TRIGGER);

  lastTime = micros();
}

// ===========================================================================
//                              LOOP
// ===========================================================================

void loop() {
  unsigned long loopStart = micros();

  unsigned long now = loopStart;
  unsigned long elapsed = now - lastTime;
  if (elapsed > 1000000UL) elapsed = LOOP_INTERVAL_US;
  float dt = elapsed / 1000000.0f;
  lastTime = now;

  // MPU Okuma
  uint8_t raw[14];
  mpuReadBytes(ACCEL_XOUT_H, raw, 14);

  float ax = (int16_t)(raw[0] << 8 | raw[1]) / 8192.0f;
  float ay = (int16_t)(raw[2] << 8 | raw[3]) / 8192.0f;
  float az = (int16_t)(raw[4] << 8 | raw[5]) / 8192.0f;

  float gx = ((int16_t)(raw[8]  << 8 | raw[9])  - gxOff) / 65.5f * DEG_TO_RAD;
  float gy = ((int16_t)(raw[10] << 8 | raw[11]) - gyOff) / 65.5f * DEG_TO_RAD;
  float gz = ((int16_t)(raw[12] << 8 | raw[13]) - gzOff) / 65.5f * DEG_TO_RAD;

  madgwick(gx, gy, gz, ax, ay, az, dt);

  // Joystick (EMA + deadzone)
  smoothJoyX = emaFilter(smoothJoyX, (float)analogRead(JOY_X), ANALOG_SMOOTH_ALPHA);
  smoothJoyY = emaFilter(smoothJoyY, (float)analogRead(JOY_Y), ANALOG_SMOOTH_ALPHA);
  pkt.joyX = applyDeadzone(map((int)smoothJoyX, 0, 4095, -512, 512), JOY_DEADZONE);
  pkt.joyY = applyDeadzone(map((int)smoothJoyY, 0, 4095, -512, 512), JOY_DEADZONE);

  // Tetik (EMA)
  smoothTrig = emaFilter(smoothTrig, (float)analogRead(TRIGGER), ANALOG_SMOOTH_ALPHA);
  pkt.trigger = map((int)smoothTrig, 0, 4095, 0, 1000);

  // Butonlar
  pkt.buttons = 0;
  if (digitalRead(JOY_SW) == LOW) pkt.buttons |= 0x01;

  // Quaternion
  pkt.qw = qw;
  pkt.qx = qx;
  pkt.qy = qy;
  pkt.qz = qz;

  // Sıra numarası
  pkt.seq = seqCounter++;

  // Gönder
  bool ok = radio.write(&pkt, sizeof(pkt));

  // Debug
  #if SERIAL_DEBUG
    if (ok) okCount++; else failCount++;

    if (millis() - lastPrint >= DEBUG_INTERVAL_MS) {
      unsigned long interval = millis() - lastPrint;
      float totalPkts = okCount + failCount;
      float loopHz = (totalPkts / interval) * 1000.0f;

      Serial.print("Hz:"); Serial.print(loopHz, 0);
      Serial.print(" OK:"); Serial.print(okCount);
      Serial.print(" FAIL:"); Serial.print(failCount);
      Serial.print(" Q:["); Serial.print(qw, 2);
      Serial.print(","); Serial.print(qx, 2);
      Serial.print(","); Serial.print(qy, 2);
      Serial.print(","); Serial.print(qz, 2);
      Serial.print("] J:"); Serial.print(pkt.joyX);
      Serial.print(","); Serial.print(pkt.joyY);
      Serial.print(" T:"); Serial.print(pkt.trigger);
      Serial.print(" Seq:"); Serial.println(pkt.seq);

      okCount = 0;
      failCount = 0;
      lastPrint = millis();
    }
  #endif

  // Sabit döngü hızı
  unsigned long loopDuration = micros() - loopStart;
  if (loopDuration < LOOP_INTERVAL_US) {
    delayMicroseconds(LOOP_INTERVAL_US - loopDuration);
  }
}

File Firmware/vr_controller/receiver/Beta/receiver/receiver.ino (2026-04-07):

/*
 * DIY VR Sağ Kol - Alıcı (Wemos D1 Mini + E01-ML01DP5)
 * 
 * Bağlantılar:
 *   E01-ML01DP5 (NRF24L01 uyumlu):
 *     SCK  → D5 (GPIO14)
 *     MISO → D6 (GPIO12)
 *     MOSI → D7 (GPIO13)
 *     CSN  → D2 (GPIO4)    ← ESKİ ÇALIŞAN KABLOLAMA
 *     CE   → D1 (GPIO5)
 *     VCC  → 3.3V
 *     GND  → GND
 * 
 * !! CSN PİNİ: Eski çalışan versiyon GPIO4 (D2) kullanıyordu.
 *    Eğer kablolamayı D8'e (GPIO15) taşıdıysan, aşağıdaki
 *    NRF_CSN değerini 15 olarak değiştir.
 * 
 * Arduino IDE ayarları:
 *   Board: LOLIN(WEMOS) D1 mini
 *   Upload Speed: 921600
 *   CPU Frequency: 80MHz
 * 
 * Kütüphaneler:
 *   - RF24 by TMRh20
 * 
 * PC'ye USB Serial üzerinden veri gönderiyor.
 * Driver beklenen format: $VR,qw,qx,qy,qz,joyX,joyY,trigger,buttons\n
 */

#include <SPI.h>
#include <RF24.h>

// ==============================================================
// PIN AYARLARI — Kablolaman hangisiyse onu kullan!
// ==============================================================
#define NRF_CE   5    // D1 = GPIO5  (her iki versiyonda da aynı)
#define NRF_CSN  4    // D2 = GPIO4  (eski çalışan kablolama)
// #define NRF_CSN  15   // D8 = GPIO15 (yeni kablolama — gerekiyorsa bunu aç)

RF24 radio(NRF_CE, NRF_CSN);
const uint64_t pipeAddr = 0xF0F0F0F0E1LL;

// Veri paketi — verici (transmitter.ino) ile BİREBİR aynı yapı
// Toplam 24 byte (packed)
struct __attribute__((packed)) ControllerPacket {
  float qw, qx, qy, qz;   // 16 byte
  int16_t joyX, joyY;      //  4 byte
  int16_t trigger;          //  2 byte
  uint8_t buttons;          //  1 byte
  uint8_t seq;              //  1 byte
};                          // = 24 byte

ControllerPacket pkt;
unsigned long lastReceive = 0;

// Paket kaybı takibi
uint8_t lastSeq = 0;
bool firstPacket = true;

void setup() {
  Serial.begin(115200);
  delay(500);
  Serial.println("VR Alici baslatiliyor...");

  if (!radio.begin()) {
    Serial.println("NRF24 BASARISIZ! CSN/CE kablolarini kontrol et.");
    while (1) { delay(1000); }
  }

  // --- VERİCİ İLE BİREBİR AYNI AYARLAR ---
  radio.setPALevel(RF24_PA_HIGH);
  radio.setDataRate(RF24_1MBPS);                    // Verici de 1Mbps
  radio.setChannel(76);                             // Verici kanal 76
  radio.setPayloadSize(sizeof(ControllerPacket));   // 24 byte
  radio.setAutoAck(true);
  radio.openReadingPipe(1, pipeAddr);
  radio.startListening();

  Serial.print("Paket boyutu: ");
  Serial.print(sizeof(ControllerPacket));
  Serial.println(" byte");
  Serial.print("Kanal: ");
  Serial.println(radio.getChannel());
  Serial.print("CSN pin: GPIO");
  Serial.println(NRF_CSN);
  Serial.println("Alici hazir, veri bekleniyor...");
}

void loop() {
  if (radio.available()) {
    radio.read(&pkt, sizeof(pkt));
    lastReceive = millis();

    // Paket kaybı tespiti
    if (!firstPacket) {
      uint8_t expected = lastSeq + 1;
      if (pkt.seq != expected) {
        uint8_t lost = pkt.seq - expected;
        Serial.print("$VR,LOST,");
        Serial.println(lost);
      }
    }
    lastSeq = pkt.seq;
    firstPacket = false;

    // PC'ye gönder — driver'ın beklediği format:
    // $VR,qw,qx,qy,qz,joyX,joyY,trigger,buttons
    Serial.print("$VR,");
    Serial.print(pkt.qw, 4); Serial.print(",");
    Serial.print(pkt.qx, 4); Serial.print(",");
    Serial.print(pkt.qy, 4); Serial.print(",");
    Serial.print(pkt.qz, 4); Serial.print(",");
    Serial.print(pkt.joyX);  Serial.print(",");
    Serial.print(pkt.joyY);  Serial.print(",");
    Serial.print(pkt.trigger); Serial.print(",");
    Serial.println(pkt.buttons);
  }

  // Timeout uyarısı
  if (millis() - lastReceive > 2000 && lastReceive > 0) {
    Serial.println("$VR,TIMEOUT");
    lastReceive = 0;
    firstPacket = true;
  }
}

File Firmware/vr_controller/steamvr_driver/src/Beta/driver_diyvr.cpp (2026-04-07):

/*
 * DIY VR Controller - SteamVR OpenVR Driver (v3.1 - fixed)
 * 
 * Düzeltmeler:
 *   - GetPose() icinde GetRawTrackedDevicePoses KALDIRILDI (deadlock!)
 *   - readLine timeout'unda port KAPATILMIYOR (eski calisan yaklasim)
 *   - ReadTotalTimeoutConstant arttirildi (100 → 500ms)
 *   - Gercek hata (ReadFile FALSE) ile timeout (0 byte) ayrimi
 *   - COM port auto-detect ($VR, imzasi aranir)
 *   - DTR/RTS koruması (Arduino reset onleme)
 *   - Thread-safe veri paylasimi (mutex)
 *
 * Debug log: C:\Users\emre_\diyvr_debug.txt
 */

#include <openvr_driver.h>
#include <windows.h>
#include <thread>
#include <atomic>
#include <mutex>
#include <string>
#include <cstring>
#include <cstdio>
#include <cmath>
#include <chrono>

using namespace vr;

// ============ DEBUG LOG ============
static FILE* g_logFile = nullptr;
static std::mutex g_logMutex;

void logMsg(const char* fmt, ...) {
    std::lock_guard<std::mutex> lock(g_logMutex);
    if (!g_logFile) {
        g_logFile = fopen("C:\\Users\\emre_\\diyvr_debug.txt", "a");
    }
    if (g_logFile) {
        SYSTEMTIME st;
        GetLocalTime(&st);
        fprintf(g_logFile, "[%02d:%02d:%02d.%03d] ",
                st.wHour, st.wMinute, st.wSecond, st.wMilliseconds);

        va_list args;
        va_start(args, fmt);
        vfprintf(g_logFile, fmt, args);
        va_end(args);
        fprintf(g_logFile, "\n");
        fflush(g_logFile);
    }
}

// ============ SERIAL PORT ============
class SerialPort {
public:
    HANDLE hSerial = INVALID_HANDLE_VALUE;

    bool isOpen() const { return hSerial != INVALID_HANDLE_VALUE; }

    bool open(const char* port, int baud) {
        char fullPath[64];
        snprintf(fullPath, sizeof(fullPath), "\\\\.\\%s", port);
        logMsg("Serial aciliyor: %s (baud=%d)", fullPath, baud);

        hSerial = CreateFileA(fullPath, GENERIC_READ | GENERIC_WRITE, 0, NULL,
                              OPEN_EXISTING, 0, NULL);
        if (hSerial == INVALID_HANDLE_VALUE) {
            logMsg("Serial HATA! CreateFile error=%lu", GetLastError());
            return false;
        }

        // DTR/RTS LOW — Arduino/Wemos reset onleme
        EscapeCommFunction(hSerial, CLRDTR);
        EscapeCommFunction(hSerial, CLRRTS);
        Sleep(50);

        DCB dcb = {};
        dcb.DCBlength = sizeof(DCB);
        GetCommState(hSerial, &dcb);
        dcb.BaudRate    = baud;
        dcb.ByteSize    = 8;
        dcb.Parity      = NOPARITY;
        dcb.StopBits    = ONESTOPBIT;
        dcb.fDtrControl = DTR_CONTROL_DISABLE;
        dcb.fRtsControl = RTS_CONTROL_DISABLE;
        dcb.fOutxCtsFlow = FALSE;
        dcb.fOutxDsrFlow = FALSE;
        dcb.fDsrSensitivity = FALSE;
        if (!SetCommState(hSerial, &dcb)) {
            logMsg("SetCommState HATA! error=%lu", GetLastError());
            CloseHandle(hSerial);
            hSerial = INVALID_HANDLE_VALUE;
            return false;
        }

        EscapeCommFunction(hSerial, CLRDTR);
        EscapeCommFunction(hSerial, CLRRTS);

        // Timeout: 500ms — Wemos'a yeterli zaman ver
        COMMTIMEOUTS timeouts = {};
        timeouts.ReadIntervalTimeout         = 50;
        timeouts.ReadTotalTimeoutMultiplier  = 0;
        timeouts.ReadTotalTimeoutConstant    = 500;
        SetCommTimeouts(hSerial, &timeouts);

        PurgeComm(hSerial, PURGE_RXCLEAR | PURGE_TXCLEAR);

        logMsg("Serial OK acildi! (DTR/RTS LOW, timeout=500ms)");
        return true;
    }

    // readLine donusleri:
    //   >0  : basarili, satir okundu
    //    0  : timeout, hic byte gelmedi (normal, port ACIK KALMALI)
    //   -1  : gercek hata, port bozulmus olabilir
    int readLine(char* outBuf, int maxLen) {
        int idx = 0;
        while (idx < maxLen - 1) {
            char c;
            DWORD bytesRead = 0;
            BOOL ok = ReadFile(hSerial, &c, 1, &bytesRead, NULL);

            if (!ok) {
                // ReadFile gercekten basarisiz oldu — port hatasi
                return -1;
            }
            if (bytesRead == 0) {
                // Timeout — hic byte gelmedi, bu normal
                // Eger hic bir sey okumadiysak 0 don
                // Eger partial okuduysak da 0 don (eksik satir at)
                return 0;
            }

            if (c == '\n') {
                outBuf[idx] = '\0';
                return idx;
            }
            if (c != '\r')
                outBuf[idx++] = c;
        }
        outBuf[idx] = '\0';
        return idx;
    }

    void close() {
        if (hSerial != INVALID_HANDLE_VALUE) {
            EscapeCommFunction(hSerial, CLRDTR);
            EscapeCommFunction(hSerial, CLRRTS);
            CloseHandle(hSerial);
            hSerial = INVALID_HANDLE_VALUE;
        }
    }
};

// ============ COM PORT AUTO-DETECT ============
static bool probePort(const char* port, int baud) {
    char fullPath[64];
    snprintf(fullPath, sizeof(fullPath), "\\\\.\\%s", port);

    HANDLE h = CreateFileA(fullPath, GENERIC_READ | GENERIC_WRITE, 0, NULL,
                           OPEN_EXISTING, 0, NULL);
    if (h == INVALID_HANDLE_VALUE) return false;

    EscapeCommFunction(h, CLRDTR);
    EscapeCommFunction(h, CLRRTS);

    DCB dcb = {};
    dcb.DCBlength = sizeof(DCB);
    GetCommState(h, &dcb);
    dcb.BaudRate    = baud;
    dcb.ByteSize    = 8;
    dcb.Parity      = NOPARITY;
    dcb.StopBits    = ONESTOPBIT;
    dcb.fDtrControl = DTR_CONTROL_DISABLE;
    dcb.fRtsControl = RTS_CONTROL_DISABLE;
    SetCommState(h, &dcb);

    COMMTIMEOUTS timeouts = {};
    timeouts.ReadIntervalTimeout        = 50;
    timeouts.ReadTotalTimeoutMultiplier = 0;
    timeouts.ReadTotalTimeoutConstant   = 500;
    SetCommTimeouts(h, &timeouts);

    PurgeComm(h, PURGE_RXCLEAR | PURGE_TXCLEAR);

    // 3 saniye boyunca "$VR," iceren satir ara
    bool found = false;
    char buf[512];
    int idx = 0;
    DWORD startTick = GetTickCount();

    while (GetTickCount() - startTick < 3000) {
        char c;
        DWORD bytesRead = 0;
        if (!ReadFile(h, &c, 1, &bytesRead, NULL) || bytesRead == 0)
            continue;
        if (c == '\n') {
            buf[idx] = '\0';
            if (strncmp(buf, "$VR,", 4) == 0) {
                found = true;
                break;
            }
            idx = 0;
        } else if (c != '\r' && idx < (int)sizeof(buf) - 1) {
            buf[idx++] = c;
        }
    }

    EscapeCommFunction(h, CLRDTR);
    EscapeCommFunction(h, CLRRTS);
    CloseHandle(h);
    return found;
}
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

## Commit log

2026-03-17 V 0.0.1
    [ArduinoProMicro.kicad_sch, DroidVR_PCB.kicad_pcb, DroidVR_PCB.kicad_sch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]
2026-04-07 V1.0 Working
    [COM-09032.step, Connections.kicad_sch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]
